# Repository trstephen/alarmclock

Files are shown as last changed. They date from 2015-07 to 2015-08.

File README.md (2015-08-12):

# alarmclock
### What is CENG 299?
CENG 299 is a second year project course at the University of Victoria. Students execute the full design cycle to create an alarm clock with mp3 audio playback capabilities. A [STM32F407VG](http://www.st.com/web/catalog/mmc/FM141/SC1169/SS1577/LN11/PF252140) microcontroller is responsible for handling I/O, decoding the mp3 and generating the audio output. A custom-designed PCB filters and amplifies the audio output from the STM and contains the circuitry for driving the 7-segment display and cleaning up button input.

### What's in the repo?
**Schematics**

Detail the four main components of the circuit design:
* I/O
* Audio amplification and filtering
* External button connections
* 7-Segment display controller

The files will open natively in  [KiCad](http://www.kicad-pcb.org/display/KICAD/KiCad+EDA+Software+Suite).

Printable schematics, with some helpful notes, are [here](kicad/schematic.pdf).

*TODO*: Include files for the PCB.

**Code**

A skeleton was provided that handles the USB On-The-Go communication and audio decoding. The bulk of the project code is in:
```
main.c
state_machine.c
buttons.c
clock_display.c
```
The included `.coproj` file will open the project in [CoIDE](http://www.coocox.org/software/coide.php) but the project should work wherever the [GCC-ARM](https://launchpad.net/gcc-arm-embedded) compiler is used.

**Known Issues**

* mp3 playback
  * Only works with 128kb/s encoding
  * Stops playback after ~2min and needs to be hard reset before playback can continue

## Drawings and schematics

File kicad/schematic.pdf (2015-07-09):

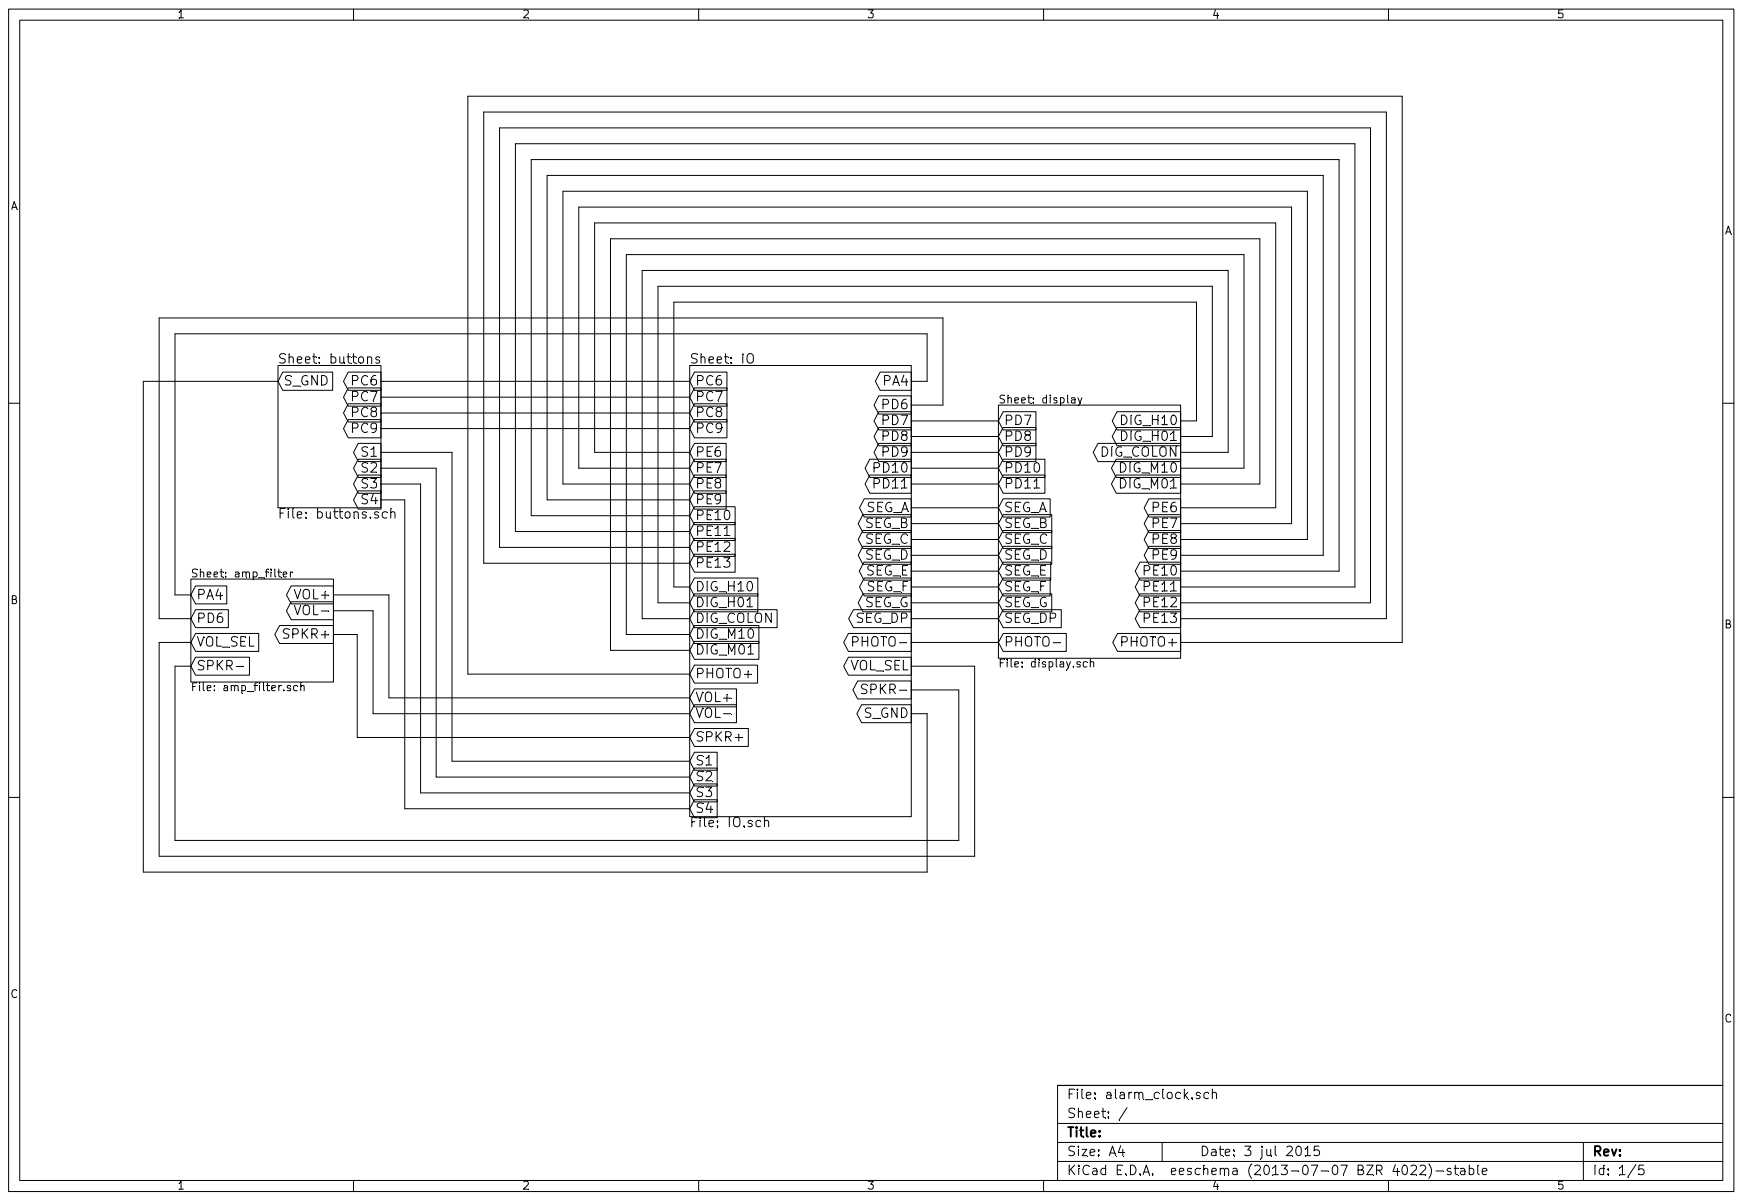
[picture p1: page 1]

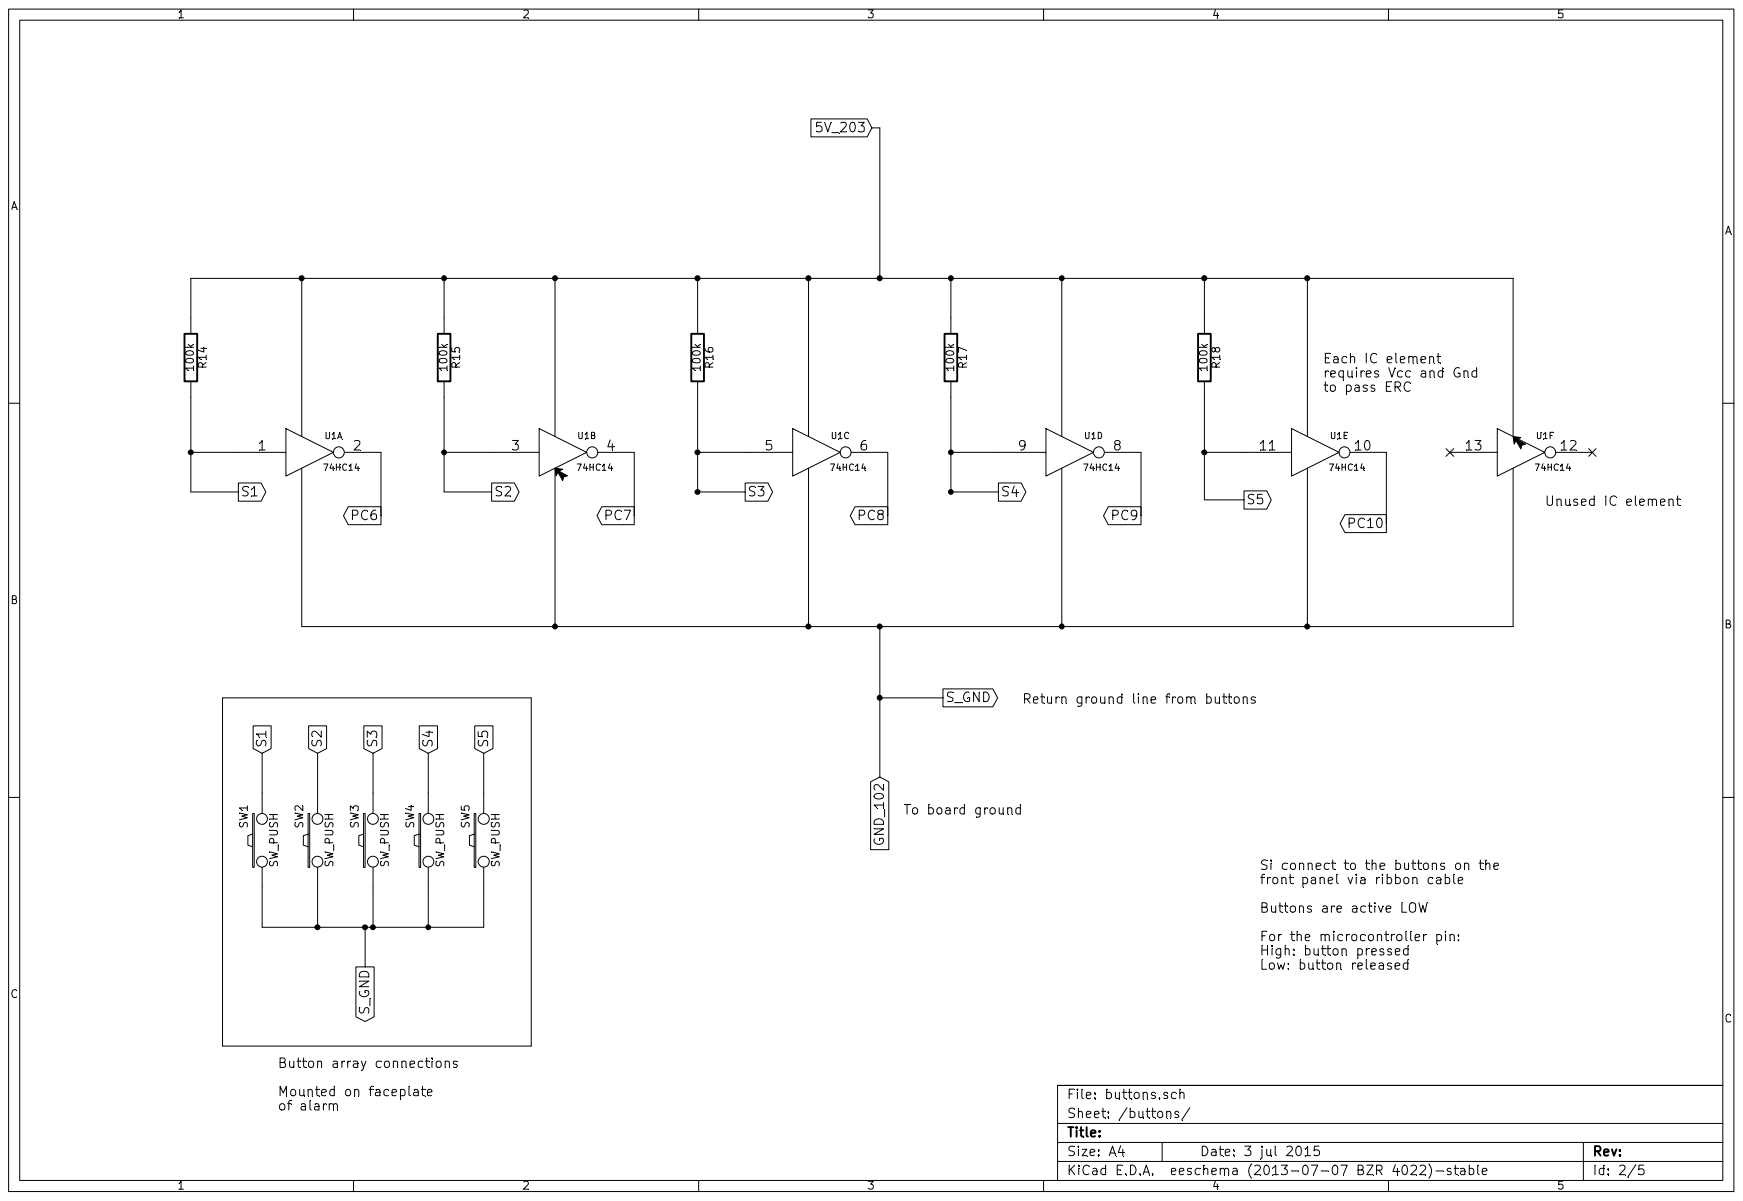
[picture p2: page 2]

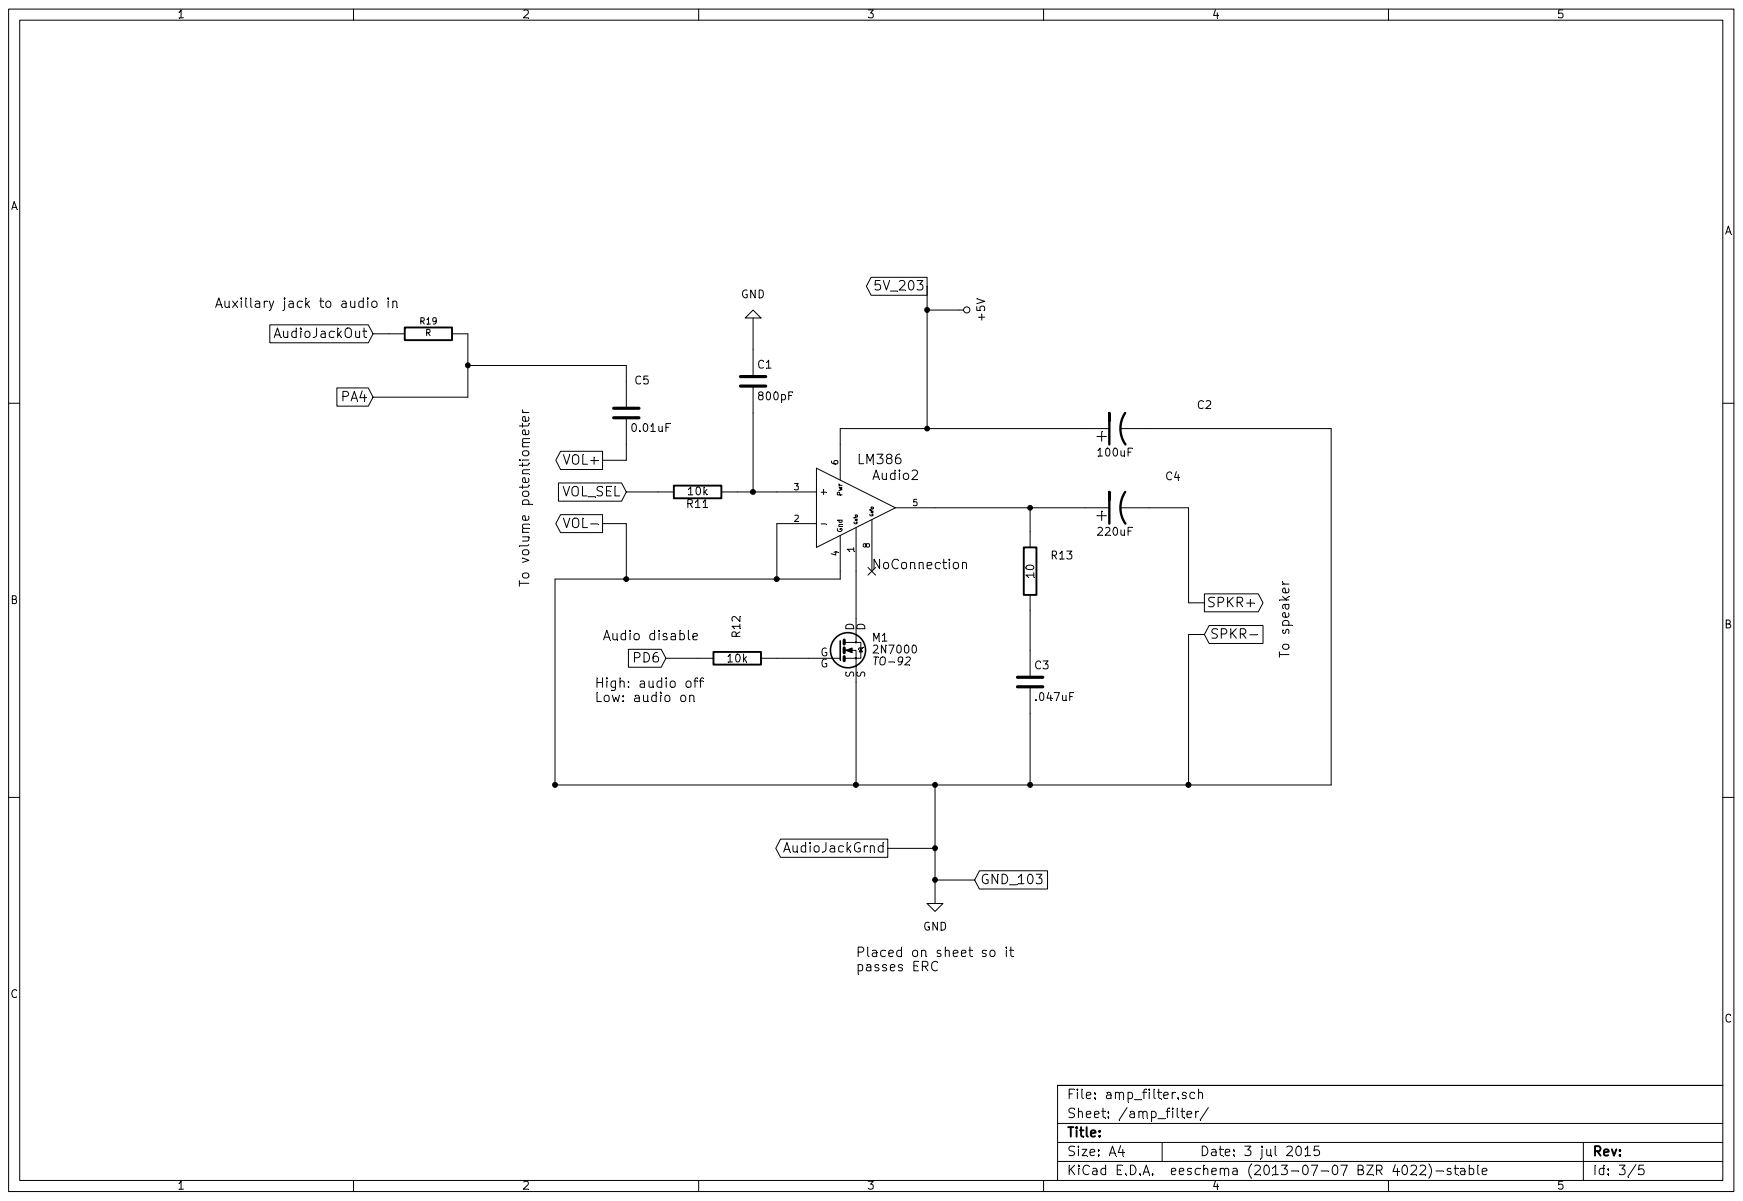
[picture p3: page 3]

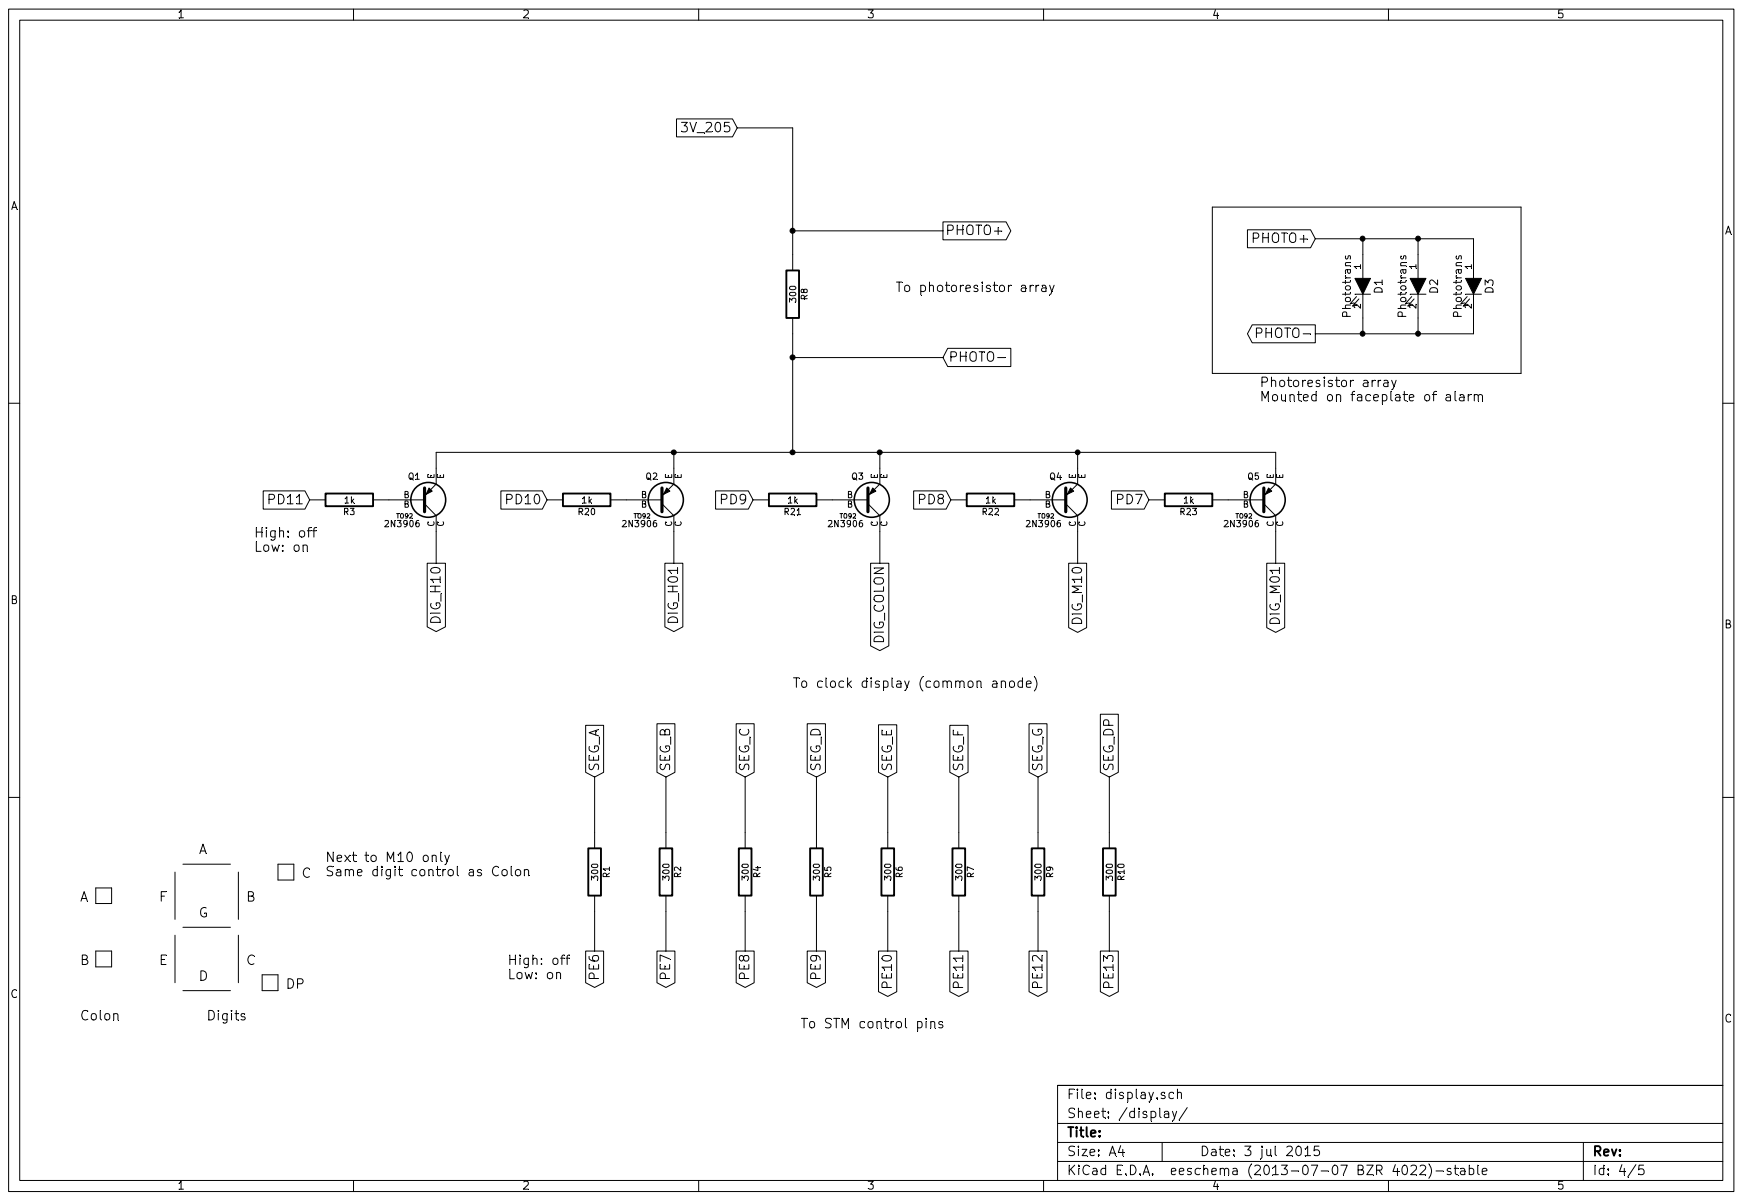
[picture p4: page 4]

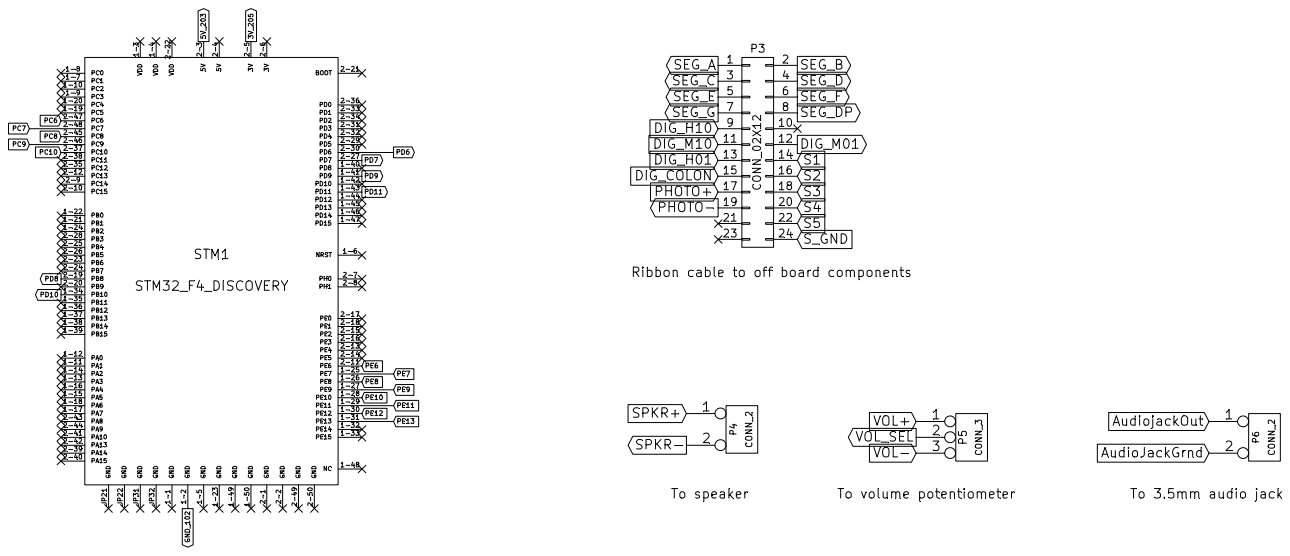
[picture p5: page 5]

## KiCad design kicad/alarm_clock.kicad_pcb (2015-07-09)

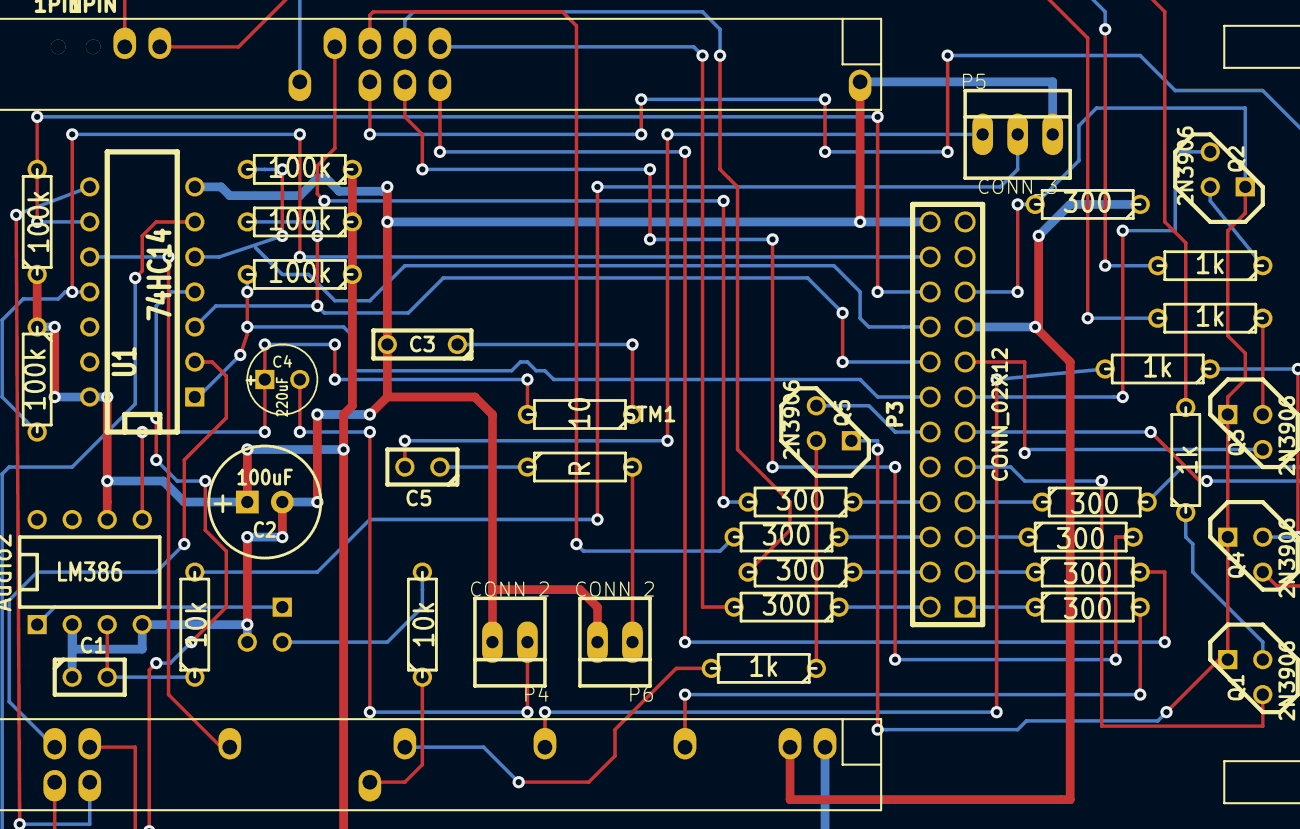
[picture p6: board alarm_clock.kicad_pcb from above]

Board: 2 copper layers, 43 parts (1 on the bottom side), 56 nets.

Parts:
1PIN, 1PIN#2: P***; 1pin
Audio2: LM386; DIP-8__300
C1: 800pF; C1
C2: 100uF; C1V8
C3: .047uF; C2
C4: 220uF; C1V5
C5: 0.01uF; C1
M1: 2N7000; TO92DGS
P3: CONN_02X12; pin_array_12x2
P4, P6: CONN_2; PINHEAD1-2
P5: CONN_3; PINHEAD1-3
Q1, Q2, Q3, Q4, Q5: 2N3906; TO92-CBE
R1, R2, R4, R5, R6, R7, R8, R9, R10: 300; R3
R3, R20, R21, R22, R23: 1k; R3
R11, R12: 10k; R3
R13: 10; R3
R14, R15, R16, R17, R18: 100k; R3
R19: R; R3
STM1: STM32_F4_DISCOVERY; STM32F4DISC
U1: 74HC14; DIP-14__300

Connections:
3V_205: P3.17, R8.1, STM1.2-5
5V_203: Audio2.6, C2.1, R14.1, R15.1, R16.1, R17.1, R18.1, STM1.2-3, U1.14
AudioIn: C5.1, R19.1
AudioJackGrnd: Audio2.2, Audio2.4, C1.1, C2.2, C3.2, M1.S, P3.24, P4.2, P5.3, P6.2, STM1.1-2, U1.7
AudiojackOut: P6.1, R19.2
DIG_COLON: P3.15, Q3.C
DIG_H01: P3.13, Q2.C
DIG_H10: P3.9, Q1.C
DIG_M01: P3.12, Q5.C
DIG_M10: P3.11, Q4.C
unnamed: Q2.B, R20.1
unnamed: Q5.B, R23.1
unnamed: Q1.B, R3.1
unnamed: Q4.B, R22.1
unnamed: Q3.B, R21.1
unnamed: C3.1, R13.1
unnamed: Audio2.5, C4.1, R13.2
unnamed: M1.G, R12.2
unnamed: Audio2.3, C1.2, R11.1
unnamed: Audio2.1, M1.D
PC6: STM1.2-47, U1.2
PC7: STM1.2-48, U1.4
PC8: STM1.2-45, U1.6
PC9: STM1.2-46, U1.8
PC10: STM1.2-37, U1.10
PD6: R12.1, STM1.2-30
PD7: R23.2, STM1.2-27
PD8: R22.2, STM1.2-19
PD9: R21.2, STM1.1-41
PD10: R20.2, STM1.1-34
PD11: R3.2, STM1.1-43
PE6: R1.2, STM1.2-11
PE7: R2.2, STM1.1-25
PE8: R4.2, STM1.1-26
PE9: R5.2, STM1.1-27
PE10: R6.2, STM1.1-28
PE11: R7.2, STM1.1-29
PE12: R9.2, STM1.1-30
PE13: R10.2, STM1.1-31
PHOTO-: P3.19, Q1.E, Q2.E, Q3.E, Q4.E, Q5.E, R8.2
S1: P3.14, R14.2, U1.1
S2: P3.16, R15.2, U1.3
S3: P3.18, R16.2, U1.5
S4: P3.20, R17.2, U1.9
S5: P3.22, R18.2, U1.11
SEG_A: P3.1, R1.1
SEG_B: P3.2, R2.1
SEG_C: P3.3, R4.1
SEG_D: P3.4, R5.1
SEG_DP: P3.8, R10.1
SEG_E: P3.5, R6.1
SEG_F: P3.6, R7.1
SEG_G: P3.7, R9.1
SPKR+: C4.2, P4.1
VOL+: C5.2, P5.1
VOL_SEL: P5.2, R11.2

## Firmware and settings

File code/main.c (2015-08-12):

//This program uses the RTC to display time on a 4 digit 7 segment display
//When the alarm triggers, it plays mp3 files through a USB connected on the
//micro USB port

#include "audioMP3.h"
#include "buttons.h"
#include "clock_display.h"
#include "main.h"
#include "misc.h"
#include "state_machine.h"
#include "stm32f4xx_dac.h"
#include "stm32f4xx_exti.h"
#include "stm32f4xx_gpio.h"
#include "stm32f4xx_pwr.h"
#include "stm32f4xx_rtc.h"
#include "stm32f4xx_rcc.h"
#include "stm32f4xx_tim.h"

/*
 * Leftover junk from the demo code
 */
RTC_TimeTypeDef		myclockTimeStruct;
RTC_AlarmTypeDef	AlarmStruct;
RTC_AlarmTypeDef 	alarmMemory;

//global variables
int interruptOccurred = 0;


extern volatile int exitMp3 = 0;
extern volatile int mp3PlayingFlag = 0;
extern volatile int snoozeMemory = 0;

/*
 * My code starts here
*/
extern volatile State_T GState = {
	.currentState = DISPLAY_RTC,
	.nextState = DISPLAY_RTC,
	.isAlarmSet = false
};

volatile ClockDisplay_T GClockDisplay = {
	.getTime_func = ClockDisplay_UpdateFromRTC,
	.hourFormat = RTC_HourFormat_12,
	.currentSegment = DIGIT_H10,
	.isColonBlinking = true,
	.isDisplayBlinking = true,
	.blinkCounter = 0
};

// Global variables for buttons
volatile Button_T GBtn_Music = {
	.pin = GPIO_Pin_6,
	.isBeingDebounced = false,
	.isPressed = false,
	.isLongPress = false,
	.shortPress_func = ButtonFunc_ToggleMusic,
	.longPress_func = ButtonFunc_ToggleAuxInput
};

volatile Button_T GBtn_Hour = {
	.pin = GPIO_Pin_7,
	.isBeingDebounced = false,
	.isPressed = false,
	.isLongPress = false,
	.shortPress_func = ButtonFunc_ToggleBlueLED,
	.longPress_func = ButtonFunc_ToggleOrangeLED
};

volatile Button_T GBtn_Minute = {
	.pin = GPIO_Pin_8,
	.isBeingDebounced = false,
	.isPressed = false,
	.isLongPress = false,
	.shortPress_func = ButtonFunc_SwapFunctions,
	.longPress_func = ButtonFunc_Disabled
};

volatile Button_T GBtn_Time = {
	.pin = GPIO_Pin_9,
	.isBeingDebounced = false,
	.isPressed = false,
	.isLongPress = false,
	.shortPress_func = ButtonFunc_ToggleHourFormat,
	.longPress_func = ButtonFunc_GetNewTime
};

volatile Button_T GBtn_Alarm = {
	.pin = GPIO_Pin_10,
	.isBeingDebounced = false,
	.isPressed = false,
	.isLongPress = false,
	.shortPress_func = ButtonFunc_ToggleAlarm,
	.longPress_func = ButtonFunc_GetAlarmTime
};

int main(void)
{
	configuration();

	Audio_Stop(); // sets initial conditions for audio control flags

	while (1)
	{
		if (mp3PlayingFlag)
		{
			audioToMp3();
		}
	}
}

//timer interrupt handler that is called at a rate of 500Hz
//this function gets the time and displays it on the 7 segment display
//it also checks for button presses, debounces, and handles each case
void TIM5_IRQHandler(void)
{
	int previousState = 0;

	//double checks that interrupt has occurred
	if( TIM_GetITStatus( TIM5, TIM_IT_Update ) != RESET )
	{
		ClockDisplay_UpdateTime();

		Buttons_PollAllButtons();

		State_UpdateState();

		//clears interrupt flag
	     TIM5->SR = (uint16_t)~TIM_IT_Update;
    }
}

//alarm A interrupt handler
//when alarm occurs, clear all the interrupt bits and flags
//then set the flag to play mp3
void RTC_Alarm_IRQHandler(void)
{

	// Alarm handler
	if(RTC_GetITStatus(RTC_IT_ALRA) != RESET)
	{
		GState.nextState = ALARM_ACTIVE;

		RTC_ClearFlag(RTC_FLAG_ALRAF);
		RTC_ClearITPendingBit(RTC_IT_ALRA);
		EXTI_ClearITPendingBit(EXTI_Line17);
		interruptOccurred = 1;
	}

	// snooze handler
	if(RTC_GetITStatus(RTC_IT_ALRB) != RESET)
	{
		GState.nextState = ALARM_ACTIVE;

		RTC_ClearFlag(RTC_FLAG_ALRBF);
		RTC_ClearITPendingBit(RTC_IT_ALRB);
		EXTI_ClearITPendingBit(EXTI_Line17);
	}
}


void configuration(void)
{
	RCC_ClocksTypeDef RCC_Clocks;
	GPIO_InitTypeDef initStruct;
	TIM_TimeBaseInitTypeDef TIM_InitStruct;
	RTC_InitTypeDef	myclockInitTypeStruct;
	RTC_TimeTypeDef initTime;
	NVIC_InitTypeDef NVIC_InitStructure;
	EXTI_InitTypeDef EXTI_InitStructure;

	//lets the system clocks be viewed
	RCC_GetClocksFreq(&RCC_Clocks);

	//enable peripheral clocks
	RCC_APB1PeriphClockCmd(RCC_APB1Periph_PWR, ENABLE);
	RCC_AHB1PeriphClockCmd(RCC_AHB1Periph_GPIOE, ENABLE);
	RCC_AHB1PeriphClockCmd(RCC_AHB1Periph_GPIOD, ENABLE);
	RCC_AHB1PeriphClockCmd(RCC_AHB1Periph_GPIOC, ENABLE);
	RCC_APB1PeriphClockCmd(RCC_APB1Periph_TIM5, ENABLE);

	//enable the RTC
	PWR_BackupAccessCmd(DISABLE);
	PWR_BackupAccessCmd(ENABLE);
	RCC_RTCCLKConfig(RCC_RTCCLKSource_LSI);
	RCC_RTCCLKCmd(ENABLE);
	RTC_AlarmCmd(RTC_Alarm_A,DISABLE);

	//Enable the LSI OSC
	RCC_LSICmd(ENABLE);

	//Wait till LSI is ready
	while(RCC_GetFlagStatus(RCC_FLAG_LSIRDY) == RESET);

	//enable the external interrupt for the RTC to use the Alarm
	/* EXTI configuration */
	EXTI_ClearITPendingBit(EXTI_Line17);
	EXTI_InitStructure.EXTI_Line = EXTI_Line17;
	EXTI_InitStructure.EXTI_Mode = EXTI_Mode_Interrupt;
	EXTI_InitStructure.EXTI_Trigger = EXTI_Trigger_Rising;
	EXTI_InitStructure.EXTI_LineCmd = ENABLE;
	EXTI_Init(&EXTI_InitStructure);

	//set timer 5 to interrupt at a rate of 500Hz
	TIM_TimeBaseStructInit(&TIM_InitStruct);
	TIM_InitStruct.TIM_Period	=  8000;	// 500Hz
	TIM_InitStruct.TIM_Prescaler = 20;
	TIM_TimeBaseInit(TIM5, &TIM_InitStruct);

	// Enable the TIM5 global Interrupt
	NVIC_Init( &NVIC_InitStructure );
	NVIC_InitStructure.NVIC_IRQChannel = TIM5_IRQn;
	NVIC_InitStructure.NVIC_IRQChannelPreemptionPriority = 0;
	NVIC_InitStructure.NVIC_IRQChannelSubPriority = 0;
	NVIC_InitStructure.NVIC_IRQChannelCmd = ENABLE;
	NVIC_Init( &NVIC_InitStructure );

	//enables timer interrupt
	TIM5->DIER |= TIM_IT_Update;
	//enables timer
	TIM5->CR1 |= TIM_CR1_CEN;

	//setup the RTC for 12 hour format
	myclockInitTypeStruct.RTC_HourFormat = RTC_HourFormat_12;
	myclockInitTypeStruct.RTC_AsynchPrediv = 127;
	myclockInitTypeStruct.RTC_SynchPrediv = 0x00FF;
	RTC_Init(&myclockInitTypeStruct);

	// initial time: 12:00 PM
	initTime.RTC_H12 = RTC_H12_AM;
	initTime.RTC_Hours = 0x012;
	initTime.RTC_Minutes = 0x00;
	initTime.RTC_Seconds = 0x00;
	RTC_SetTime(RTC_Format_BCD, &initTime);


	//sets alarmA for 12:00AM, date doesn't matter
	GAlarm.RTC_AlarmTime.RTC_H12 = RTC_H12_AM;
	GAlarm.RTC_AlarmTime.RTC_Hours = 0x012;
	GAlarm.RTC_AlarmTime.RTC_Minutes = 0x00;
	GAlarm.RTC_AlarmTime.RTC_Seconds = 0x000;
	GAlarm.RTC_AlarmMask = RTC_AlarmMask_DateWeekDay;
	RTC_SetAlarm(RTC_Format_BCD,RTC_Alarm_A,&GAlarm);

	// Enable the Alarm global Interrupt
	NVIC_Init( &NVIC_InitStructure );
	NVIC_InitStructure.NVIC_IRQChannel = RTC_Alarm_IRQn;
	NVIC_InitStructure.NVIC_IRQChannelPreemptionPriority = 0;
	NVIC_InitStructure.NVIC_IRQChannelSubPriority = 0;
	NVIC_InitStructure.NVIC_IRQChannelCmd = ENABLE;
	NVIC_Init( &NVIC_InitStructure );

	//enables RTC alarm A interrupt
	RTC_ITConfig(RTC_IT_ALRA, ENABLE);
	RTC_ITConfig(RTC_IT_ALRB, ENABLE);

	Buttons_Init();

	Audio_Init();

	ClockDisplay_Init();
}

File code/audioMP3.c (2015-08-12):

#include "audioMP3.h"
#include "core_cm4.h"
#include "stm32f4xx_conf.h"
#include "mp3dec.h"
#include "Audio.h"
#include <string.h>
#include "main.h"

// Macros
#define f_tell(fp)		((fp)->fptr)

// Variables
volatile uint32_t		time_var1, time_var2;
USB_OTG_CORE_HANDLE		USB_OTG_Core;
USBH_HOST				USB_Host;
RCC_ClocksTypeDef		RCC_Clocks;
volatile int			enum_done = 0;

// MP3 Variables
#define FILE_READ_BUFFER_SIZE   2000
#define AUDIO_LOCAL_BUFFER_SIZE 2304
#define NUMBER_BUFFERS			12
#define AUDIO_INT_BUFFER		2304

MP3FrameInfo			mp3FrameInfo;
HMP3Decoder				hMP3Decoder;
FIL						file;
int16_t					audio_read_buffer[AUDIO_LOCAL_BUFFER_SIZE * NUMBER_BUFFERS];
uint					audio_buffer_length[NUMBER_BUFFERS];
volatile uint			buffer_read;
volatile uint			buffer_write;
bool                    running_player;

// Private function prototypes
static void AudioCallback(void *context,int buffer);
static uint32_t Mp3ReadId3V2Tag(FIL* pInFile, char* pszArtist,
		uint32_t unArtistSize, char* pszTitle, uint32_t unTitleSize);
static bool fill_mp3_buffer(FIL *fp, int buffer_number, bool reset);
static void play_mp3(char* filename);
static FRESULT play_directory (const char* path, unsigned char seek);

void Audio_Start()
{
	mp3PlayingFlag = 1;
	exitMp3 = 0;
	GPIO_ResetBits(GPIOD, GPIO_Pin_6); // enable LM386
}

void Audio_Stop()
{
	mp3PlayingFlag = 0;
	exitMp3 = 1;
	GPIO_SetBits(GPIOD, GPIO_Pin_6); // disable LM386
}

/*
 * Main function. Called when startup code is done with
 * copying memory and setting up clocks.
 */
int audioToMp3(void) {
	GPIO_InitTypeDef  GPIO_InitStructure;

	// SysTick interrupt each 1ms
	RCC_GetClocksFreq(&RCC_Clocks);
	SysTick_Config(RCC_Clocks.HCLK_Frequency / 1000);

	// GPIOD Peripheral clock enable
	RCC_AHB1PeriphClockCmd(RCC_AHB1Periph_GPIOD, ENABLE);

	// Configure PD12, PD13, PD14 and PD15 in output pushpull mode
	GPIO_InitStructure.GPIO_Pin = GPIO_Pin_12 | GPIO_Pin_13 | GPIO_Pin_14 | GPIO_Pin_15;
	GPIO_InitStructure.GPIO_Mode = GPIO_Mode_OUT;
	GPIO_InitStructure.GPIO_OType = GPIO_OType_PP;
	GPIO_InitStructure.GPIO_Speed = GPIO_Speed_100MHz;
	GPIO_InitStructure.GPIO_PuPd = GPIO_PuPd_NOPULL;
	GPIO_Init(GPIOD, &GPIO_InitStructure);

	// Initialize USB Host Library
	USBH_Init(&USB_OTG_Core, USB_OTG_FS_CORE_ID, &USB_Host, &USBH_MSC_cb, &USR_Callbacks);

	for(;;) {
		if(0==exitMp3)
		{
			USBH_Process(&USB_OTG_Core, &USB_Host);

			if (enum_done >= 2) {
				enum_done = 0;
				play_directory("", 0);
			}
		}
		//exit and disable peripherals
		else
		{
			//RTC_AlarmCmd(RTC_Alarm_A,DISABLE);
			DAC_Cmd(DAC_Channel_1, DISABLE);
			DAC_DMACmd(DAC_Channel_1, DISABLE); //DMAEN1
			DMA_Cmd(DMA1_Stream5, DISABLE);
			TIM_Cmd(TIM6, DISABLE);


			exitMp3 = 0;
			mp3PlayingFlag = 0;
			break;
		}
	}
}

const char *get_filename_ext(const char *filename) {
    const char *dot = strrchr(filename, '.');
    if(!dot || dot == filename) return "";
    return dot + 1;
}

static FRESULT play_directory (const char* path, unsigned char seek) {
	FRESULT res;
	FILINFO fno;
	DIR dir;
	char *fn; /* This function is assuming non-Unicode cfg. */
	char buffer[200];
#if _USE_LFN
	static char lfn[_MAX_LFN + 1];
	fno.lfname = lfn;
	fno.lfsize = sizeof(lfn);
#endif


	res = f_opendir(&dir, path); /* Open the directory */
	if (res == FR_OK) {
		for (;;) {

			if(0 == exitMp3)
			{
				res = f_readdir(&dir, &fno); /* Read a directory item */
				if (res != FR_OK || fno.fname[0] == 0) break; /* Break on error or end of dir */
				if (fno.fname[0] == '.') continue; /* Ignore dot entry */
	#if _USE_LFN
				fn = *fno.lfname ? fno.lfname : fno.fname;
	#else
				fn = fno.fname;
	#endif
				if (fno.fattrib & AM_DIR) { /* It is a directory */

				} else { /* It is a file. */
					sprintf(buffer, "%s/%s", path, fn);

					// Check if it is an mp3 file
					if (strcmp("MP3", get_filename_ext(buffer)) == 0) {


						// Skip "seek" number of mp3 files...
						if (seek) {
							seek--;
							continue;
						}

						play_mp3(buffer);
					}
				}
			}
			else
			{
				break;
			}
		}
	}

	return res;
}

/*
static int fill_wav_buffer(FIL *fp) {
	unsigned int br,btr;
	static int16_t    file_read_buffer[FILE_READ_BUFFER_SIZE];
	static int16_t    *file_read_ptr = file_read_buffer;
    static uint       number_samples = 0;

	FRESULT        res;
	int            err;
	int            outOfData = 0;
	int            copy_samples;

	// Turn on blue LED to indicate decoding start.
	GPIO_SetBits(GPIOD, GPIO_Pin_15);

	// Disable audio callback interrupt.
	NVIC_DisableIRQ(DMA1_Stream7_IRQn);

	// Copy audio samples to front of the buffer
	copy_samples = write_ptr - read_ptr;
	memmove(audio_read_buffer, read_ptr, sizeof(int16_t) * copy_samples);
	write_ptr = audio_read_buffer + copy_samples;
	read_ptr = audio_read_buffer;

	// Copy extra samples into buffer
	memcpy(write_ptr,file_read_buffer, sizeof(int16_t) * number_samples );
	write_ptr += number_samples;

	// Enable audio callback interrupt.
	NVIC_EnableIRQ(DMA1_Stream7_IRQn);

	do {
		// Fill the file read buffer
		btr = sizeof(int16_t) * FILE_READ_BUFFER_SIZE;
		res = f_read(fp, file_read_buffer , btr, &br);
		number_samples = br/sizeof(int16_t);

		if ( write_ptr - audio_read_buffer + number_samples > AUDIO_READ_BUFFER_SIZE ) {
			copy_samples = AUDIO_READ_BUFFER_SIZE - ( write_ptr - audio_read_buffer );
		} else {
			copy_samples = number_samples;
		}

		memcpy(write_ptr,file_read_buffer,sizeof(int16_t) * copy_samples );
		write_ptr += copy_samples;
		number_samples -= copy_samples;


		if ( number_samples > 0  ) {
			memmove(file_read_buffer,file_read_buffer + copy_samples, sizeof(int16_t) * number_samples);
		}

		outOfData = f_eof(fp);

	} while( res == FR_OK && !outOfData && number_samples == 0  );

	// Turn off blue LED to indicate decoding finish.
	GPIO_ResetBits(GPIOD, GPIO_Pin_15);

	return(outOfData);
}
*/
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

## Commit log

2015-06-07 clocktest()
    Lights all segments on the clock, one digit at a time. Untested on the
    board! Compiles, but who knows what it does....
2015-06-08 Creation of clock_display
    Extracted GPIO configuration from main into clock_display.
    Test method now lives in clock_display.
    Hooks for new functions are in main but are commented out.
    Untested on the board!
2015-06-09 Interrupt sequence fixed
    Gotta clear the interrupt flag last.
    Files c/p'd from the lab machine; lots of commits of files that are
    unchanged! No more working on the lab machine :(
    [main.c]
2015-06-09 Revert "Interrupt sequence fixed"
    This reverts commit e7e204ce43aa066f86588d32e030751ee9580d98.
    [main.c]
2015-06-09 Actually fixed interrupt sequence
    Come on, no conflicts :(
    [main.c]
2015-06-18 add kicad files
    [$test.sch, HexSchmitt.sch, IO backup.sch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]
2015-06-19 initial routing
    [alarm_clockCopperTrackAdded.kicad_pcb]
2015-06-19 Drill hole sizes fixed
    Match APCircuits free sizes
    Header holes deleted D:
    [alarm_clockBestSoFar.kicad_pcb, alarm_clockRemovedNC's.kicad_pcb, alarm_clockTouchedupBACKUP.kicad_pcb]
2015-06-20 Final routing
    Removed some intermediary routing steps, too
    [IO.sch, PBNOCicuitsch.sch, SchmittTrigger.sch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]
2015-06-20 New pcb file
    How did this not get syncd?
    [alarm_clock.kicad_pcb]
2015-07-09 Add audio enable pin
2015-07-09 Final schematics
    Also includes pdf
2015-07-09 Button stubs
    Added basic button interrupt handler. C10 toggles onboard LED.
2015-07-15 Button struct added
    Mmm, global variables. All over this project.
2015-07-15 Display array
    Condensed all of the constants for the display pins into an array. Makes
    it a bit cleaner? Gets rid of the switch statement for assigning
    display digits from decimal values.
2015-07-18 New button handling *untested*
    Buttons are now checked through polling
2015-07-18 *untested* Function pointers for button presses
    Implementing the long/short button press functions via function pointers
    to functions from the state machine.
    Cleaned up some of the old external interrupt methods for button
    presses.
    [buttons.c, main.c]
2015-07-19 Fixed 10s digit time display
    [buttons.c, clock_display.c, main.c]
2015-07-20 Button debouncing working
2015-07-20 Added ClockDisplay struct
    setting the groundwork for making an extensible clock display. the clock
    display update is a function pointer which will point to the appropriate
    time to display (RTC, alarm, set time)
2015-07-21 *untested* Button functions refactor
    Button functions can only change the global state and do minor flag
    changes (12/24 hr; incr time). The state machine is responsible for
    changing button functions and display functions.
2015-07-25 *broken* New audio processor
    Supposed to solve a skipping problem with mono tracks. Initial testing
    was negative.
    Attempting to pause or stop audio playback causes skipping.
    [audioMP3.c, buttons.c, clock_display.c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]
2015-07-25 Comments!
    So much commenting…
2015-07-30 Corrected audio playback
    It was mainly a sample rate error. The "fix" is to use a 128 kbps mp3
    for playback~
    [audioMP3.c, buttons.c, clock_display.c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]
2015-08-12 *Fix* Snooze reactivates
    Fixed bug where snooze would trigger once and then not again.
    [buttons.c, main.c]
2015-08-12 Updated readme
    It’s actually helpful now.
2015-08-12 *Fix* Missing IO pins
    Added PA4 to the schematic IO page and fixed PD8, PD10
    [IO backup.sch, IO.sch, IO_backup.sch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]
